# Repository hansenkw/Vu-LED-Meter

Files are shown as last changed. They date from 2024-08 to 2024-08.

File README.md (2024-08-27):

# Vu-LED-Meter
This is a decorative LED that shines based on the audio input through the 3.5mm audio jack connector. The design is a 2-layer printed circuit board (PCB) based on Great Scott Vu LED Meter (https://www.instructables.com/Make-Your-Own-LED-Sign-VU-Meter/) with few modifications as seen below. 
  - Changed through-hole (THT) to surface-mounted (SMD) components, allowing space-effiecient design.
  - Designed a 12V-5V DCDC buck converter circuitry instead of using off the shelf module, integrated it with the rest of the circuitry into one PCB.
  - Utilized six (instead of seven) audio voltage references with each associated with a single row of LEDs.
  - Addeed current-limiting resistors to reduce current consumption.

# Overview

# Schematic Design

# Layout

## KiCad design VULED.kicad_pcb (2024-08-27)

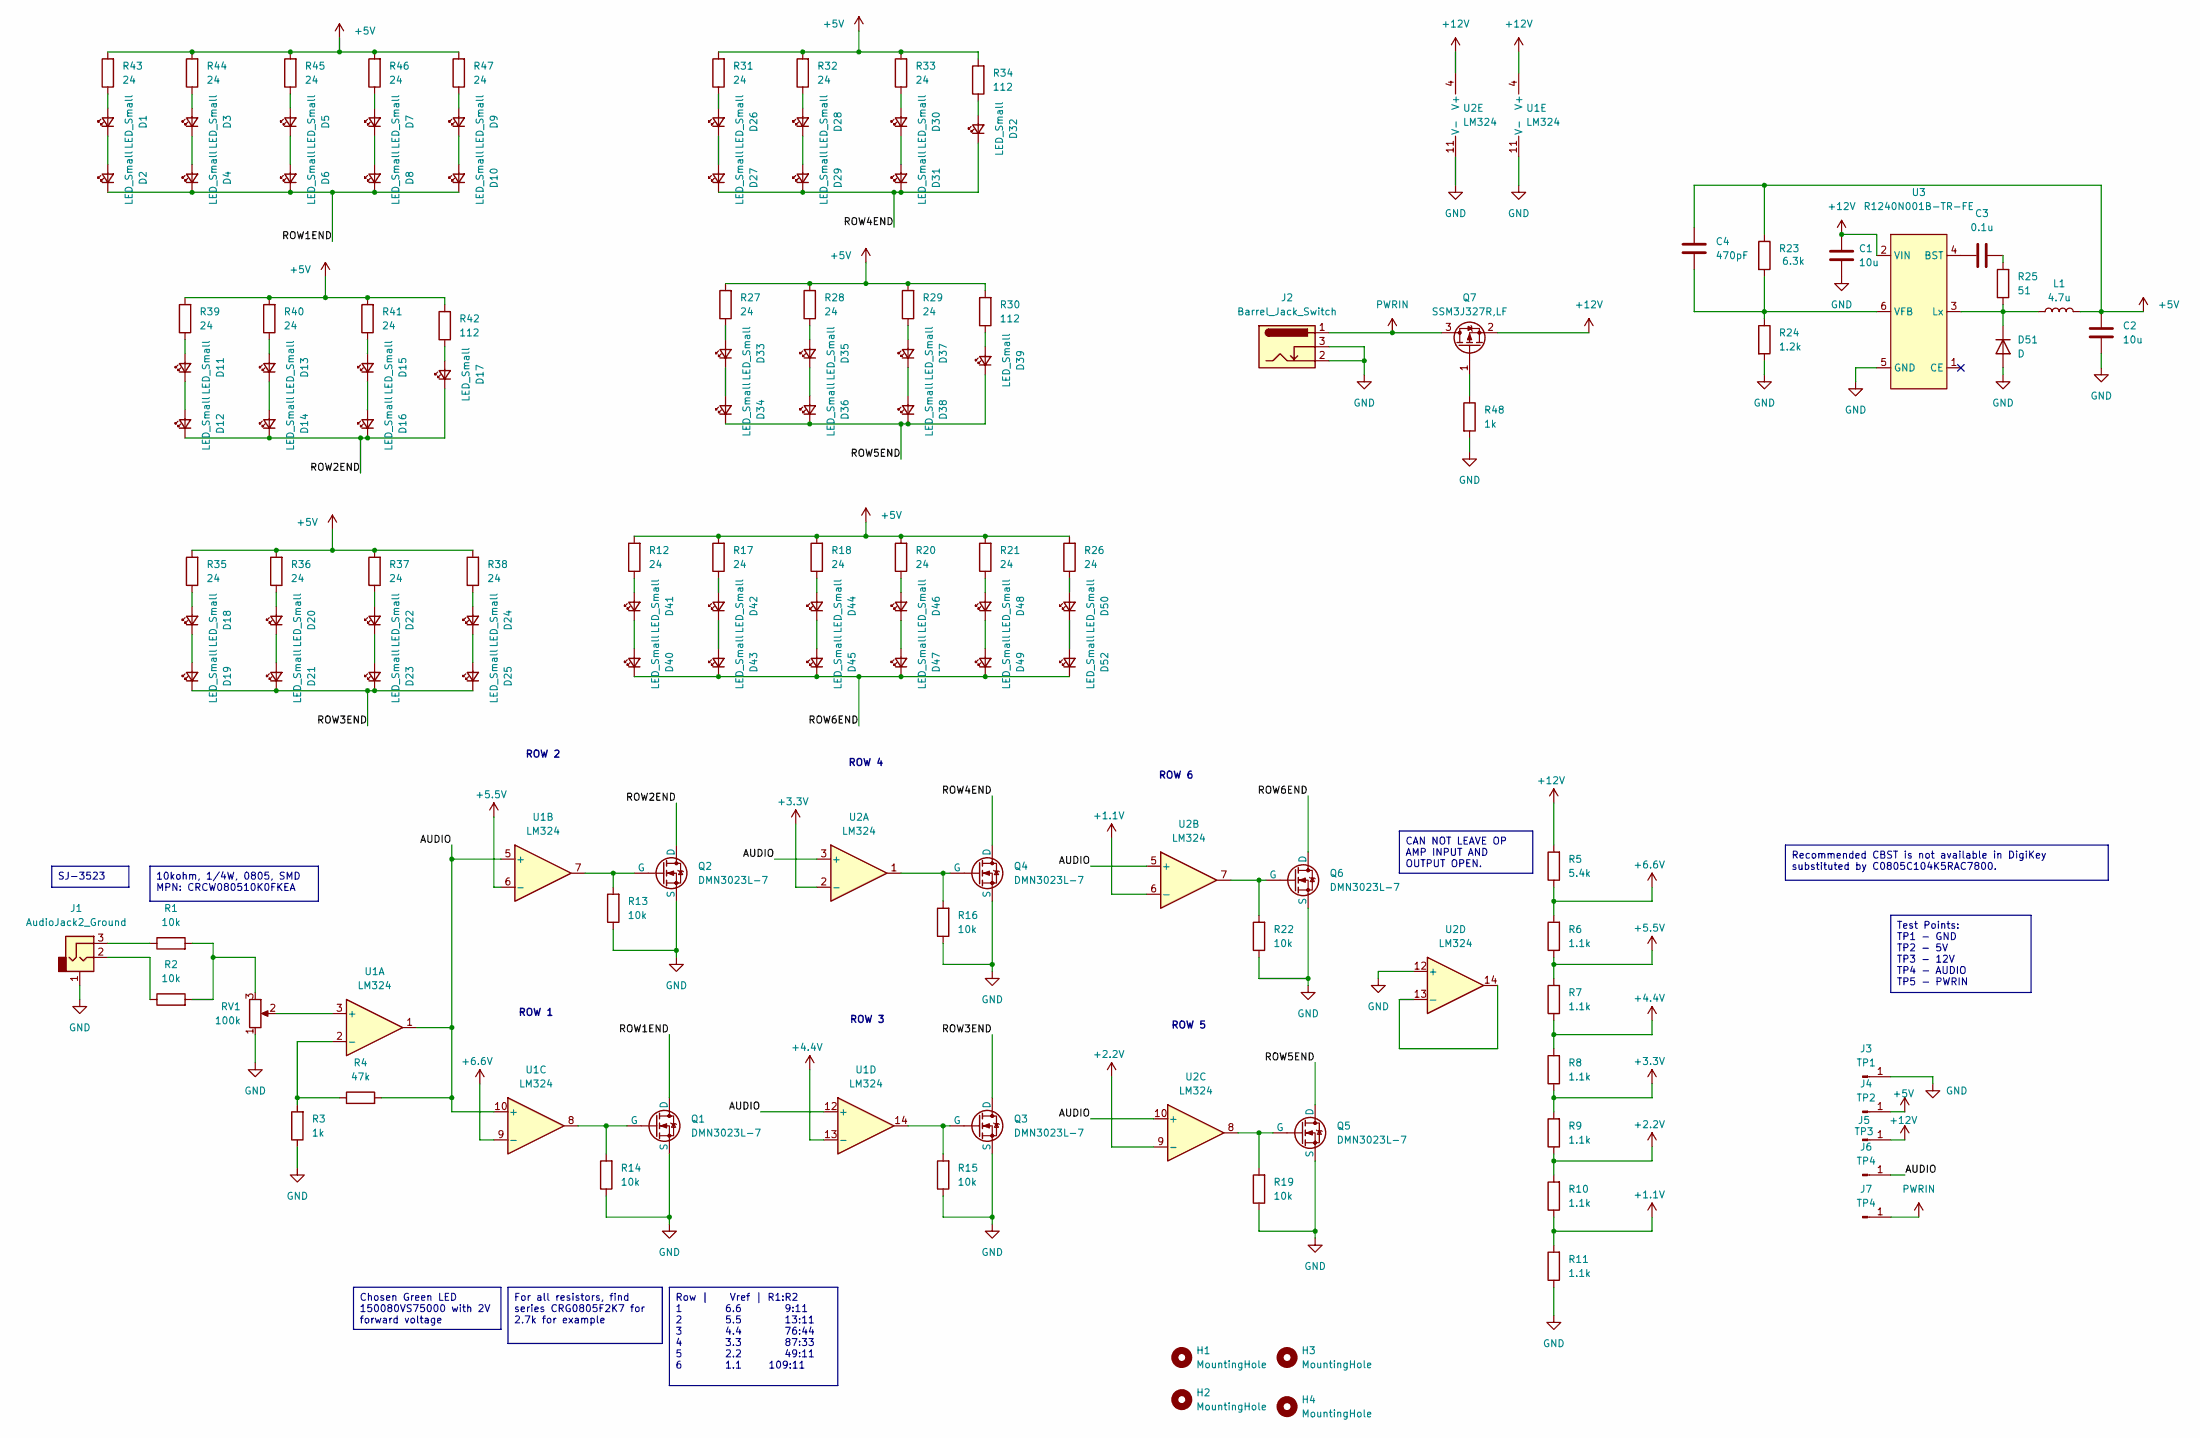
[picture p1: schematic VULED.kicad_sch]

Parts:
C1: 10u; KTS500B106M55N0T00
C2: 10u; GRM31CR71E106KA12L
C3: 0.1u; C0805C104K5RACTU
C4: 470pF; C_0201_0603Metric
D1, D2, D3, D4, D5, D6, D7, D8, D9, D10, D11, D12, D13, D14, D15, D16, D17, D18, D19, D20, D21, D22, D23, D24, D25, D26, D27, D28, D29, D30, D31, D32, D33, D34, D35, D36, D37, D38, D39, D40, D41, D42, D43, D44, D45, D46, D47, D48, D49, D50, D52: LED_Small; 150080VS75000-WL-SMCW_0805
D51: D; CMS11
H1, H2, H3, H4: MountingHole; M3-Mounting Holes
J1: AudioJack2_Ground; STX-3000_KYC
J2: Barrel_Jack_Switch; EJ508A
J3: TP1; PH1_01_UA
J4: TP2; PH1_01_UA
J5: TP3; PH1_01_UA
J6, J7: TP4; PH1_01_UA
L1: 4.7u; IND_SLF7045T-4R7M2R0-PF
Q1, Q2, Q3, Q4, Q5, Q6: DMN3023L-7; DMN3023L_7
Q7: SSM3J327R,LF; SSM3J327R-LF
R1, R2: 10k; RESC2012X50N
R3, R48: 1k; RES0805_CRG_TYCO_TYC
R4: 47k; RES0805_CRG_TYCO_TYC
R5: 5.4k; RES0805_CRG_TYCO_TYC
R6, R7, R8, R9, R10, R11: 1.1k; RES0805_CRG_TYCO_TYC
R12, R17, R18, R20, R21, R26, R27, R28, R29, R31, R32, R33, R35, R36, R37, R38, R39, R40, R41, R43, R44, R45, R46, R47: 24; CPF0603B24RE1
R13, R14, R15, R16, R19, R22: 10k; RES0805_CRG_TYCO_TYC
R23: 6.3k; RES0805_CRG_TYCO_TYC
R24: 1.2k; RES0805_CRG_TYCO_TYC
R25: 51; RC0805FR-0751RL
R30, R34, R42: 112; RES0805_CRG_TYCO_TYC
RV1: 100k; POT_PTA3043_BRN
U1: LM324; LM324-D14-M
U2: LM324
U3: R1240N001B-TR-FE; SOT-23-6W_PE-SOT23-6W-0512_NMD

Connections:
+1.1V: R10.1, R11.2, U2.6 (-)
+2.2V: R9.1, R10.2, U2.9 (-)
+3.3V: R8.1, R9.2, U2.2 (-)
+4.4V: R7.1, R8.2, U1.13 (-)
+5.5V: R6.1, R7.2, U1.6 (-)
+5V: C2.1, C4.1, J4.1, L1.2, R12.2, R17.2, R18.2, R20.2, R21.2, R23.1, R26.2, R27.2, R28.2, R29.2, R30.2, R31.2, R32.2, R33.2, R34.2, R35.2, R36.2, R37.2, R38.2, R39.2, R40.2, R41.2, R42.2, R43.2, R44.2, R45.2, R46.2, R47.2
+6.6V: R5.1, R6.2, U1.9 (-)
+12V: C1.1, J5.1, Q7.2 (S), R5.2, U1.4 (V+), U2.4 (V+), U3.2 (VIN)
/AUDIO: J6.1, R4.2, U1.1, U1.5 (+), U1.10 (+), U1.12 (+), U2.3 (+), U2.5 (+), U2.10 (+)
/ROW1END: D2.1 (K), D4.1 (K), D6.1 (K), D8.1 (K), D10.1 (K), Q1.1 (D)
/ROW2END: D12.1 (K), D14.1 (K), D16.1 (K), D17.1 (K), Q2.1 (D)
/ROW3END: D19.1 (K), D21.1 (K), D23.1 (K), D25.1 (K), Q3.1 (D)
/ROW4END: D27.1 (K), D29.1 (K), D31.1 (K), D32.1 (K), Q4.1 (D)
/ROW5END: D34.1 (K), D36.1 (K), D38.1 (K), D39.1 (K), Q5.1 (D)
/ROW6END: D40.1 (K), D43.1 (K), D45.1 (K), D47.1 (K), D49.1 (K), D52.1 (K), Q6.1 (D)
GND: C1.2, C2.2, D51.2 (A), J1.1, J2.2, J2.3, J3.1, Q1.3 (S), Q2.3 (S), Q3.3 (S), Q4.3 (S), Q5.3 (S), Q6.3 (S), R3.1, R11.1, R13.1, R14.1, R15.1, R16.1, R19.1, R22.1, R24.2, R48.2, RV1.1, U1.11 (V-), U2.11 (V-), U2.12 (+), U3.5 (GND)
unnamed: C3.2, R25.2
unnamed: D1.2 (A), R43.1
unnamed: D1.1 (K), D2.2 (A)
unnamed: D3.2 (A), R44.1
unnamed: D3.1 (K), D4.2 (A)
unnamed: D5.2 (A), R45.1
unnamed: D5.1 (K), D6.2 (A)
unnamed: D7.2 (A), R46.1
unnamed: D7.1 (K), D8.2 (A)
unnamed: D9.2 (A), R47.1
unnamed: D9.1 (K), D10.2 (A)
unnamed: D11.2 (A), R39.1
unnamed: D11.1 (K), D12.2 (A)
unnamed: D13.2 (A), R40.1
unnamed: D13.1 (K), D14.2 (A)
unnamed: D15.2 (A), R41.1
unnamed: D15.1 (K), D16.2 (A)
unnamed: D17.2 (A), R42.1
unnamed: D18.2 (A), R35.1
unnamed: D18.1 (K), D19.2 (A)
unnamed: D20.2 (A), R36.1
unnamed: D20.1 (K), D21.2 (A)
unnamed: D22.2 (A), R37.1
unnamed: D22.1 (K), D23.2 (A)
unnamed: D24.2 (A), R38.1
unnamed: D24.1 (K), D25.2 (A)
unnamed: D26.2 (A), R31.1
unnamed: D26.1 (K), D27.2 (A)
unnamed: D28.2 (A), R32.1
unnamed: D28.1 (K), D29.2 (A)
unnamed: D30.2 (A), R33.1
unnamed: D30.1 (K), D31.2 (A)
unnamed: D32.2 (A), R34.1
unnamed: D33.2 (A), R27.1
unnamed: D33.1 (K), D34.2 (A)
unnamed: D35.2 (A), R28.1
unnamed: D35.1 (K), D36.2 (A)
unnamed: D37.2 (A), R29.1
unnamed: D37.1 (K), D38.2 (A)
unnamed: D39.2 (A), R30.1
unnamed: D40.2 (A), D41.1 (K)
unnamed: D41.2 (A), R12.1
unnamed: D42.2 (A), R17.1
unnamed: D42.1 (K), D43.2 (A)
unnamed: D44.2 (A), R18.1
unnamed: D44.1 (K), D45.2 (A)
unnamed: D46.2 (A), R20.1
unnamed: D46.1 (K), D47.2 (A)
unnamed: D48.2 (A), R21.1
unnamed: D48.1 (K), D49.2 (A)
unnamed: D50.2 (A), R26.1
unnamed: D50.1 (K), D52.2 (A)
unnamed: D51.1 (K), L1.1, R25.1, U3.3 (Lx)
unnamed: J1.2, R2.1
unnamed: J1.3, R1.1
unnamed: Q1.2 (G), R14.2, U1.8
unnamed: Q2.2 (G), R13.2, U1.7
unnamed: Q3.2 (G), R15.2, U1.14
unnamed: Q4.2 (G), R16.2, U2.1
unnamed: Q5.2 (G), R19.2, U2.8
unnamed: Q6.2 (G), R22.2, U2.7
unnamed: Q7.1 (G), R48.1
unnamed: R1.2, R2.2, RV1.3
unnamed: RV1.2, U1.3 (+)
unnamed: R3.2, R4.1, U1.2 (-)
unnamed: C3.1, U3.4 (BST)
unnamed: C4.2, R23.2, R24.1, U3.6 (VFB)
PWRIN: J2.1, J7.1, Q7.3 (D)

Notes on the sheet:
Row | Vref | R1:R2 1 6.6 9:11 2 5.5 13:11 3 4.4 76:44 4 3.3 87:33 5 2.2 49:11 6 1.1 109:11
SJ-3523
Chosen Green LED 150080VS75000 with 2V forward voltage
Test Points: TP1 - GND TP2 - 5V TP3 - 12V TP4 - AUDIO TP5 - PWRIN
10kohm, 1/4W, 0805, SMD MPN: CRCW080510K0FKEA
For all resistors, find series CRG0805F2K7 for 2.7k for example
CAN NOT LEAVE OP AMP INPUT AND OUTPUT OPEN.
Recommended CBST is not available in DigiKey substituted by C0805C104K5RAC7800.
ROW 2
ROW 3
ROW 5
ROW 1
ROW 4
ROW 6

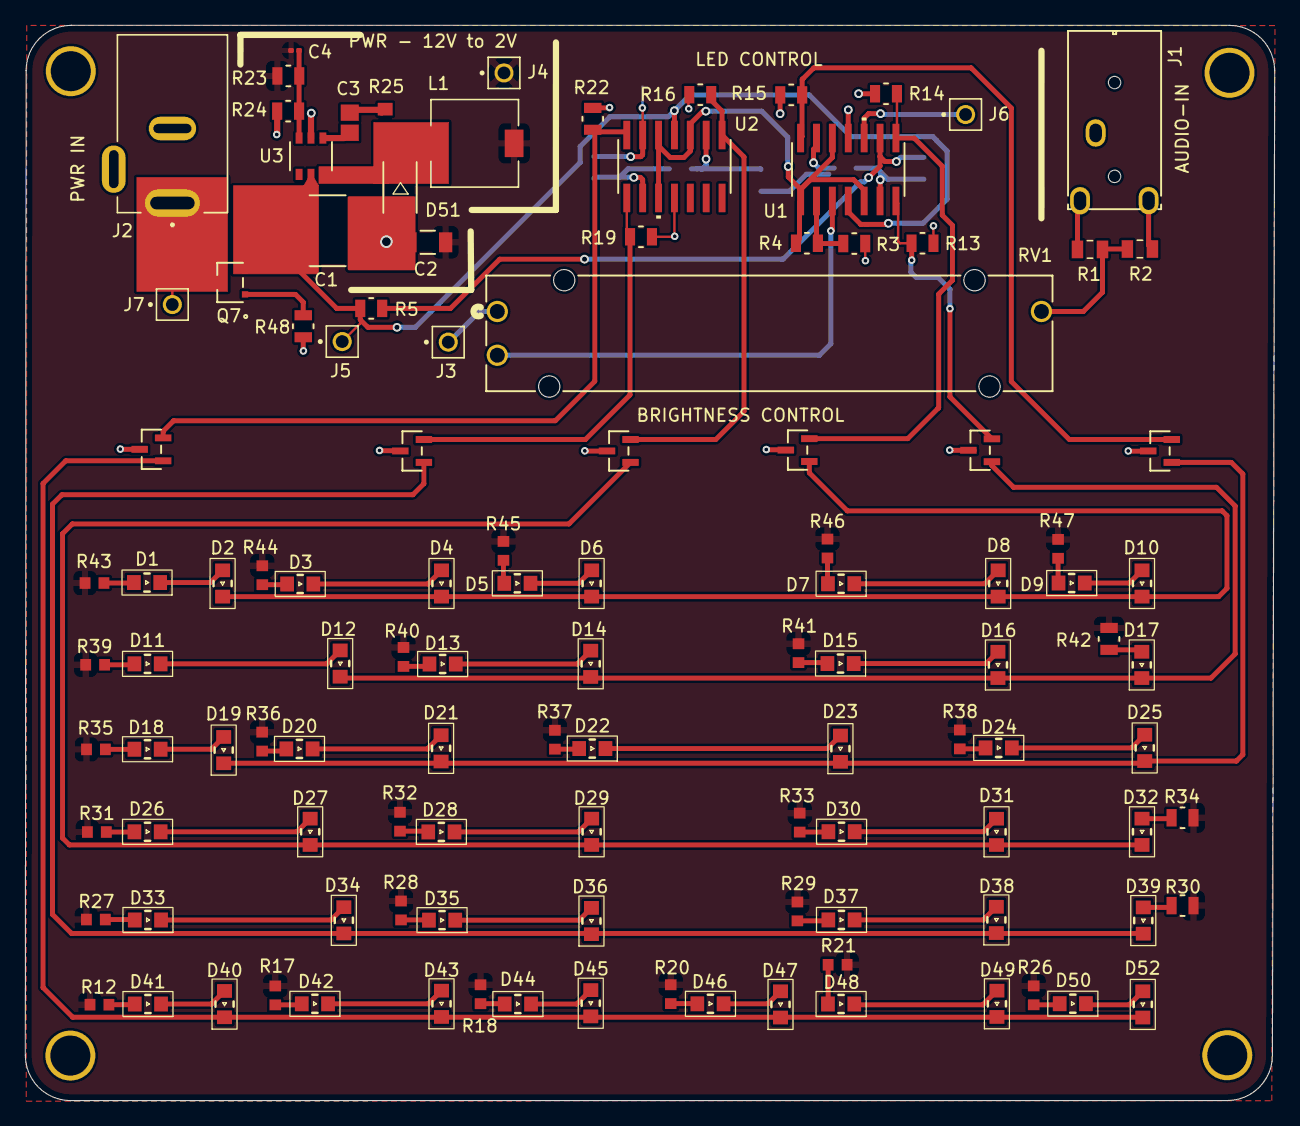
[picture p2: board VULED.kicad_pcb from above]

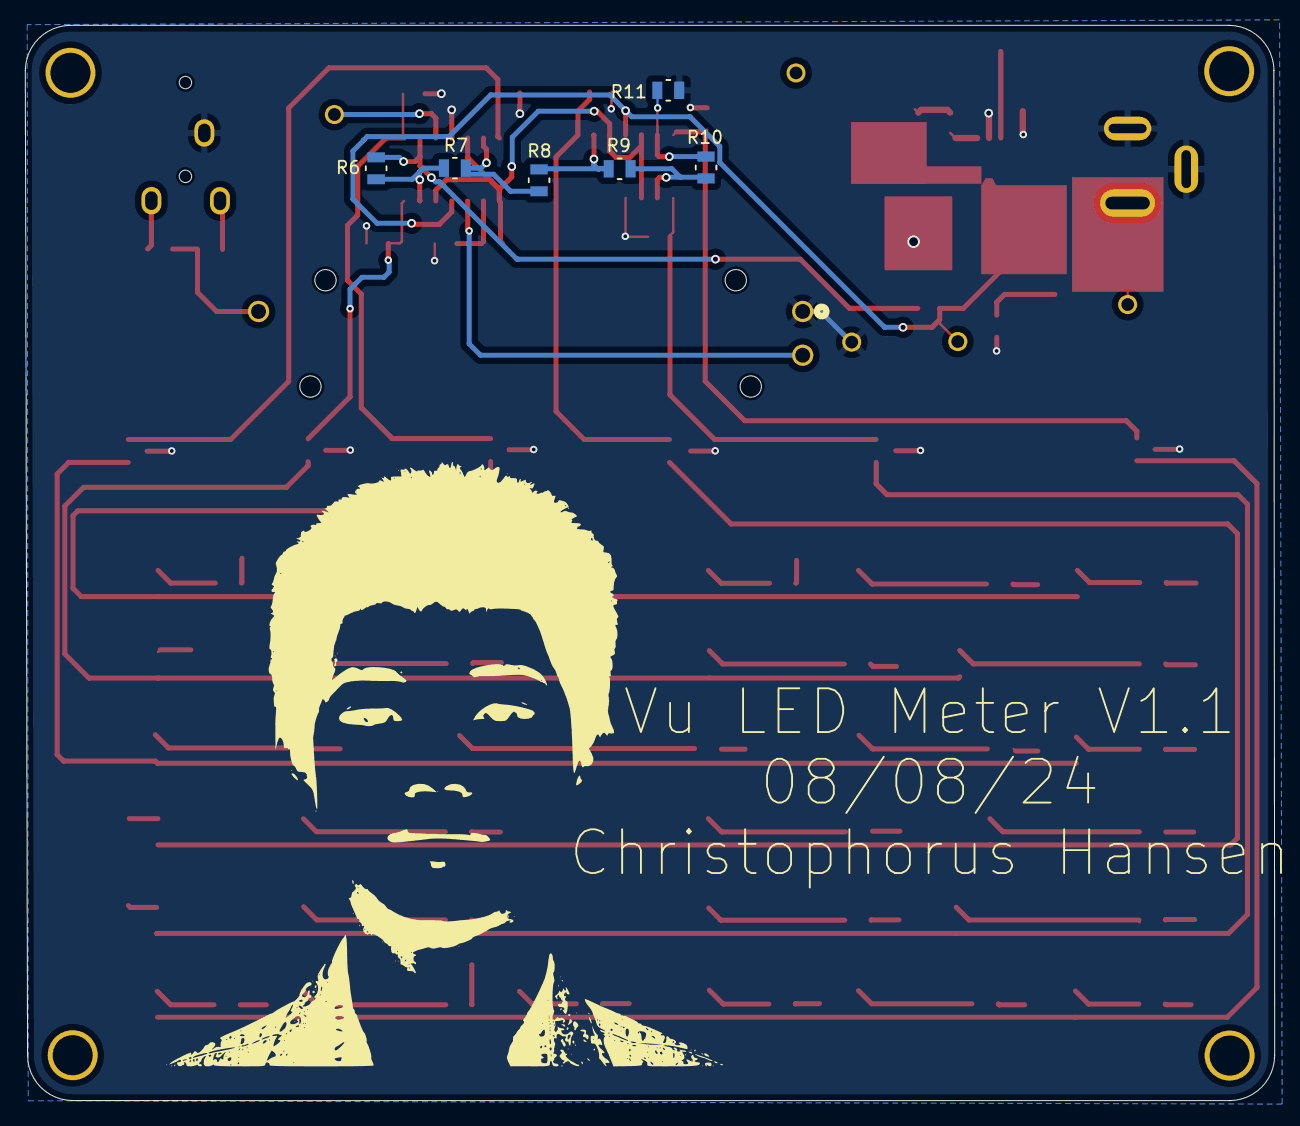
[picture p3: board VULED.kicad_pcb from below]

Board: 2 copper layers, 99.9 x 86.0 mm, 127 parts (6 on the bottom side), 84 nets.
